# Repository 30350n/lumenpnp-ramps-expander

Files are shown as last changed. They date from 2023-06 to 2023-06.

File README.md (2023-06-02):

## LumenPnP Ramps Expander

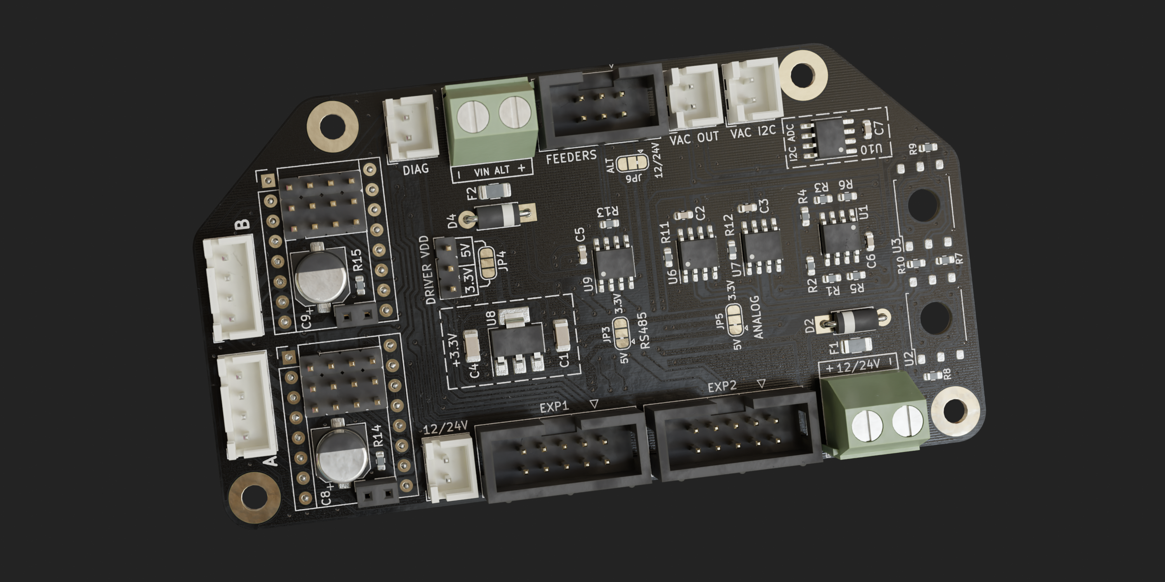
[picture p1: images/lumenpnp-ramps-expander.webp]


**Warning: This design hasn't been ordered/tested yet. Use at your own risk.**

I created this board to use as an expander for the MKS Gen L v2.1 I use to as a motherboard for
my LumenPnP.

It offers:

- 2 additional stepper drivers
- RS485 driver for feeders
- analog REV03 style vacuum sensors (I2C ADC option)
- extra power input to power feeders from a different (12V) PSU

While this was originally designed for the MKS Gen L v2.1, it should generally be compatible
with all ATmega2560 based RAMPS boards and maybe even other 3d printer boards that have the
12864 display expansion connectors.

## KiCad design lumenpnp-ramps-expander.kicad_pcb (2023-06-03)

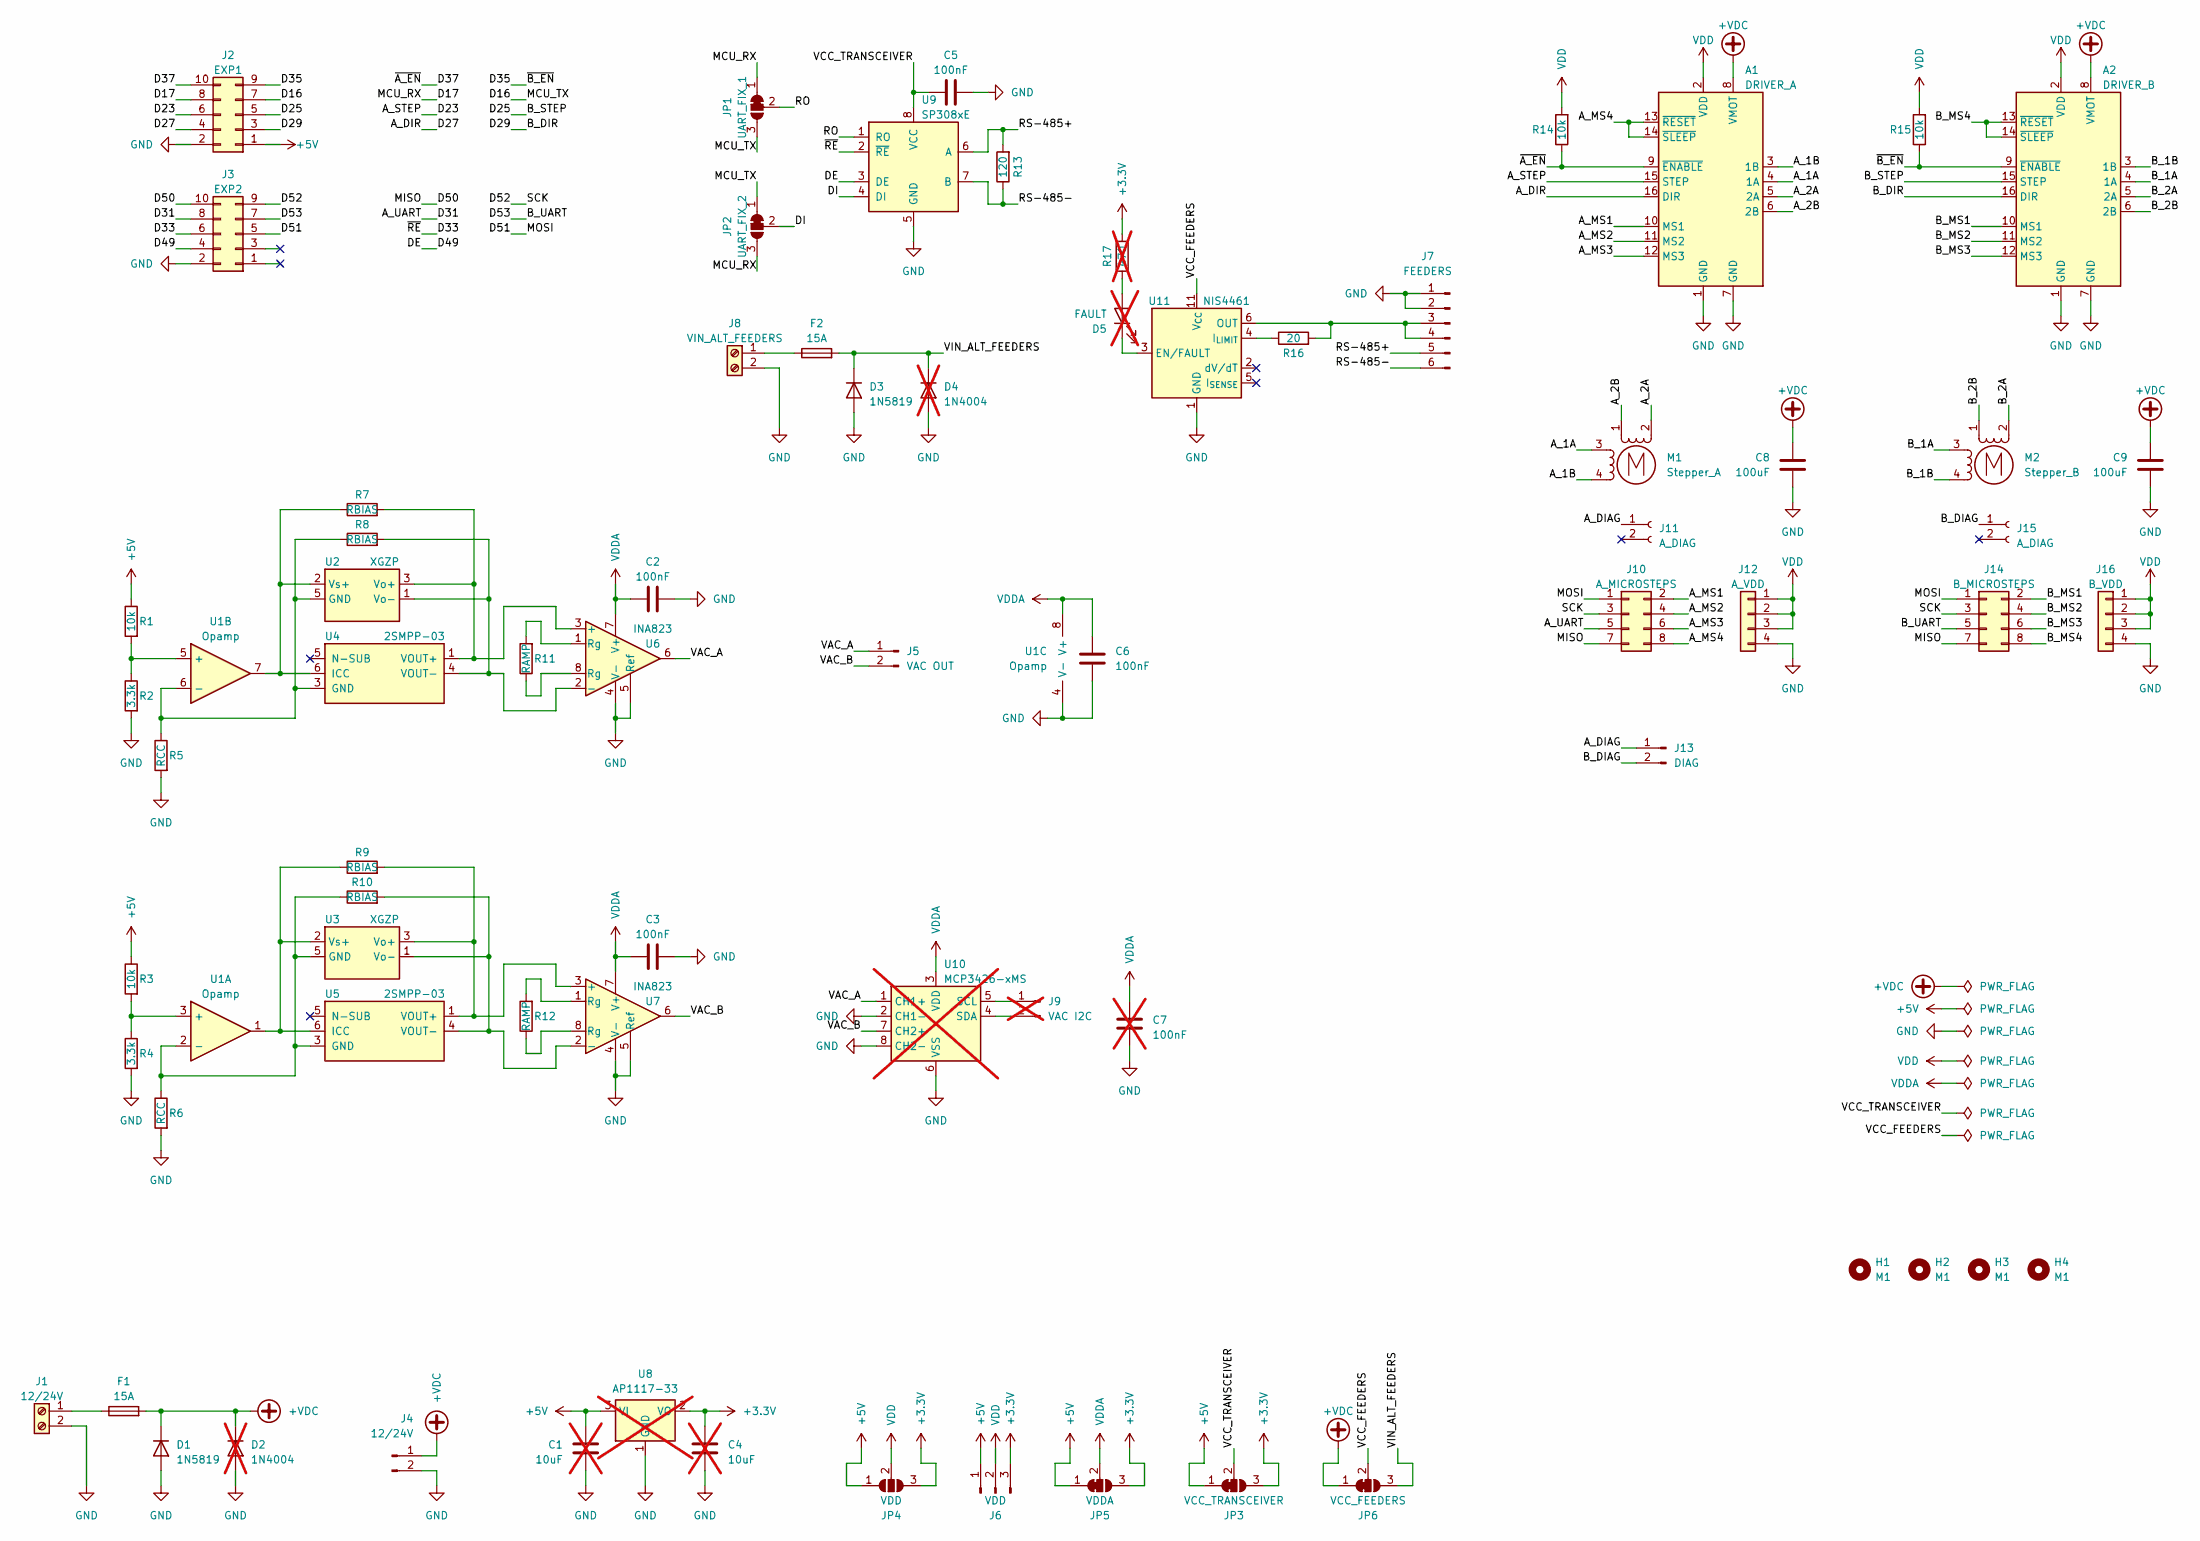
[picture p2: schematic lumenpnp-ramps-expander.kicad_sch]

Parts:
A1: DRIVER_A; Pololu_Breakout-16_15.2x20.3mm
A2: DRIVER_B; Pololu_Breakout-16_15.2x20.3mm
C1, C4: 10uF; C_1206_3216Metric; not fitted
C2, C3, C5, C6: 100nF; C_0603_1608Metric
C7: 100nF; C_0603_1608Metric; not fitted
C8, C9: 100uF; CP_Elec_6.3x7.7
D1, D3: 1N5819; D_SOD-123
D2, D4: 1N4004; D_DO-41_SOD81_P7.62mm_Horizontal; not fitted
D5: FAULT; LED_0603_1608Metric; not fitted
F1, F2: 15A; Fuse_1206_3216Metric
H1, H2, H3, H4: M1; MountingHole_3.2mm_M3_Pad
J1: 12/24V; TerminalBlock_Phoenix_MKDS-1,5-2-5.08_1x02_P5.08mm_Horizont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
J2: EXP1; IDC-Header_2x05_P2.54mm_Vertical
J3: EXP2; IDC-Header_2x05_P2.54mm_Vertical
J4: 12/24V; JST_XH_B2B-XH-A_1x02_P2.50mm_Vertical
J5: VAC OUT; JST_XH_B2B-XH-A_1x02_P2.50mm_Vertical
J6: VDD; PinHeader_1x03_P2.54mm_Vertical
J7: FEEDERS; IDC-Header_2x03_P2.54mm_Vertical
J8: VIN_ALT_FEEDERS; TerminalBlock_Phoenix_MKDS-1,5-2-5.08_1x02_P5.08mm_Horizont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
J9: VAC I2C; JST_XH_B2B-XH-A_1x02_P2.50mm_Vertical; not fitted
J10: A_MICROSTEPS; PinHeader_2x04_P2.54mm_Vertical
J11, J15: A_DIAG; PinSocket_1x02_P2.54mm_Vertical
J12: A_VDD; PinHeader_1x04_P2.54mm_Vertical
J13: DIAG; JST_XH_B2B-XH-A_1x02_P2.50mm_Vertical
J14: B_MICROSTEPS; PinHeader_2x04_P2.54mm_Vertical
J16: B_VDD; PinHeader_1x04_P2.54mm_Vertical
JP1: UART_FIX_1; SolderJumper-3_P1.3mm_Bridged12_RoundedPad1.0x1.5mm
JP2: UART_FIX_2; SolderJumper-3_P1.3mm_Bridged12_RoundedPad1.0x1.5mm
JP3: VCC_TRANSCEIVER; SolderJumper-3_P1.3mm_Bridged12_RoundedPad1.0x1.5mm
JP4: VDD; SolderJumper-3_P1.3mm_Open_RoundedPad1.0x1.5mm_NumberLabels
JP5: VDDA; SolderJumper-3_P1.3mm_Bridged12_RoundedPad1.0x1.5mm
JP6: VCC_FEEDERS; SolderJumper-3_P1.3mm_Bridged12_RoundedPad1.0x1.5mm
M1: Stepper_A; JST_XH_B4B-XH-A_1x04_P2.50mm_Vertical
M2: Stepper_B; JST_XH_B4B-XH-A_1x04_P2.50mm_Vertical
R1, R3, R14, R15: 10k; R_0603_1608Metric
R2, R4: 3.3k; R_0603_1608Metric
R5, R6: RCC; R_0603_1608Metric
R7, R8, R9, R10: RBIAS; R_0603_1608Metric
R11, R12: RAMP; R_0603_1608Metric
R13: 120; R_0603_1608Metric
R16: 20; R_0603_1608Metric
R17: 470; R_0603_1608Metric; not fitted
U1: Opamp; SOIC-8_3.9x4.9mm_P1.27mm
U2, U3: XGZP; SO-6_7x7mm_P2.54mm
U4, U5: 2SMPP-03
U6, U7: INA823; SOIC-8_3.9x4.9mm_P1.27mm
U8: AP1117-33; SOT-223-3_TabPin2; not fitted
U9: SP308xE; SOIC-8_3.9x4.9mm_P1.27mm
U10: MCP3426-xMS; SOIC-8_3.9x4.9mm_P1.27mm; not fitted
U11: NIS4461; WDFN-10-1EP_3x3mm_P0.5mm_EP1.8x2.5mm

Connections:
+3.3V: C4.1, J6.3, JP3.3 (B), JP4.3 (B), JP5.3 (B), R17.2, U8.2 (VO)
+5V: C1.1, J2.1, J6.1, JP3.1 (A), JP4.1 (A), JP5.1 (A), R1.1, R3.1, U8.3 (VI)
+VDC: A1.8 (VMOT), A2.8 (VMOT), C8.1, C9.1, D1.1 (K), D2.1 (K), F1.2, J4.1, JP6.1 (A)
/A_1A: A1.4 (1A), M1.3
/A_1B: A1.3 (1B), M1.4
/A_2A: A1.5 (2A), M1.2 (-)
/A_2B: A1.6 (2B), M1.1
/A_DIAG: J11.1, J13.1
/A_DIR: A1.16 (DIR), J2.4
/A_MS1: A1.10 (MS1), J10.2
/A_MS2: A1.11 (MS2), J10.4
/A_MS3: A1.12 (MS3), J10.6
/A_MS4: A1.13 (~RESET), A1.14 (~SLEEP), J10.8
/A_STEP: A1.15 (STEP), J2.6
/A_UART: J3.8, J10.5
/B_1A: A2.4 (1A), M2.3
/B_1B: A2.3 (1B), M2.4
/B_2A: A2.5 (2A), M2.2 (-)
/B_2B: A2.6 (2B), M2.1
/B_DIAG: J13.2, J15.1
/B_DIR: A2.16 (DIR), J2.3
/B_MS1: A2.10 (MS1), J14.2
/B_MS2: A2.11 (MS2), J14.4
/B_MS3: A2.12 (MS3), J14.6
/B_MS4: A2.13 (~RESET), A2.14 (~SLEEP), J14.8
/B_STEP: A2.15 (STEP), J2.5
/B_UART: J3.7, J14.5
/D16: J2.7, JP1.3 (B), JP2.1 (A)
/D17: J2.8, JP1.1 (A), JP2.3 (B)
/D33: J3.6, U9.2 (~RE)
/D35: A2.9 (~ENABLE), J2.9, R15.1
/D37: A1.9 (~ENABLE), J2.10, R14.1
/D49: J3.4, U9.3 (DE)
/D50: J3.10, J10.7, J14.7
/D51: J3.5, J10.1, J14.1
/D52: J3.9, J10.3, J14.3
/DI: JP2.2 (C), U9.4 (DI)
/RO: JP1.2 (C), U9.1 (RO)
/RS-485+: J7.5, R13.2, U9.6 (A)
/RS-485-: J7.6, R13.1, U9.7 (B)
/VAC_A: J5.1, U6.6, U10.1 (CH1+)
/VAC_B: J5.2, U7.6, U10.7 (CH2+)
/VCC_FEEDERS: JP6.2 (C), U11.11 (V_{CC})
/VCC_TRANSCEIVER: C5.1, JP3.2 (C), U9.8 (VCC)
/VIN_ALT_FEEDERS: D3.1 (K), D4.1 (K), F2.2, JP6.3 (B)
GND: A1.1 (GND), A1.7 (GND), A2.1 (GND), A2.7 (GND), C1.2, C2.2, C3.2, C4.2, C5.2, C6.2, C7.2, C8.2, C9.2, D1.2 (A), D2.2 (A), D3.2 (A), D4.2 (A), J1.2, J2.2, J3.2, J4.2, J7.1, J7.2, J8.2, J12.4, J16.4, R2.2, R4.2, R5.2, R6.2, U1.4 (V-), U6.4 (V-), U6.5 (Ref), U7.4 (V-), U7.5 (Ref), U8.1 (GND), U9.5 (GND), U10.2 (CH1-), U10.6 (VSS), U10.8 (CH2-), U11.1 (GND)
unnamed: D5.2 (A), R17.1
unnamed: D5.1 (K), U11.3 (EN/FAULT)
unnamed: F1.1, J1.1
unnamed: J7.3, J7.4, R16.2, U11.6 (OUT), U11.7 (OUT), U11.8 (OUT), U11.9 (OUT), U11.10 (OUT)
unnamed: F2.1, J8.1
unnamed: J9.1, U10.5 (SCL)
unnamed: J9.2, U10.4 (SDA)
unnamed: R11.1, U6.8 (Rg)
unnamed: R11.2, U6.1 (Rg)
unnamed: R12.1, U7.8 (Rg)
unnamed: R12.2, U7.1 (Rg)
unnamed: R3.2, R4.1, U1.3 (+)
unnamed: R6.1, R10.1, U1.2 (-), U3.5 (GND), U5.3 (GND)
unnamed: R1.2, R2.1, U1.5 (+)
unnamed: R5.1, R8.1, U1.6 (-), U2.5 (GND), U4.3 (GND)
unnamed: R7.2, U2.3 (Vo+), U4.1 (VOUT+), U6.3 (+)
unnamed: R7.1, U1.7, U2.2 (Vs+), U4.6 (ICC)
unnamed: R9.2, U3.3 (Vo+), U5.1 (VOUT+), U7.3 (+)
unnamed: R9.1, U1.1, U3.2 (Vs+), U5.6 (ICC)
unnamed: R8.2, U2.1 (Vo-), U2.6 (Vo-), U4.4 (VOUT-), U6.2 (-)
unnamed: R10.2, U3.1 (Vo-), U3.6 (Vo-), U5.4 (VOUT-), U7.2 (-)
unnamed: R16.1, U11.4 (I_{LIMIT})
VDD: A1.2 (VDD), A2.2 (VDD), J6.2, J12.1, J12.2, J12.3, J16.1, J16.2, J16.3, JP4.2 (C), R14.2, R15.2
VDDA: C2.1, C3.1, C6.1, C7.1, JP5.2 (C), U1.8 (V+), U6.7 (V+), U7.7 (V+), U10.3 (VDD)

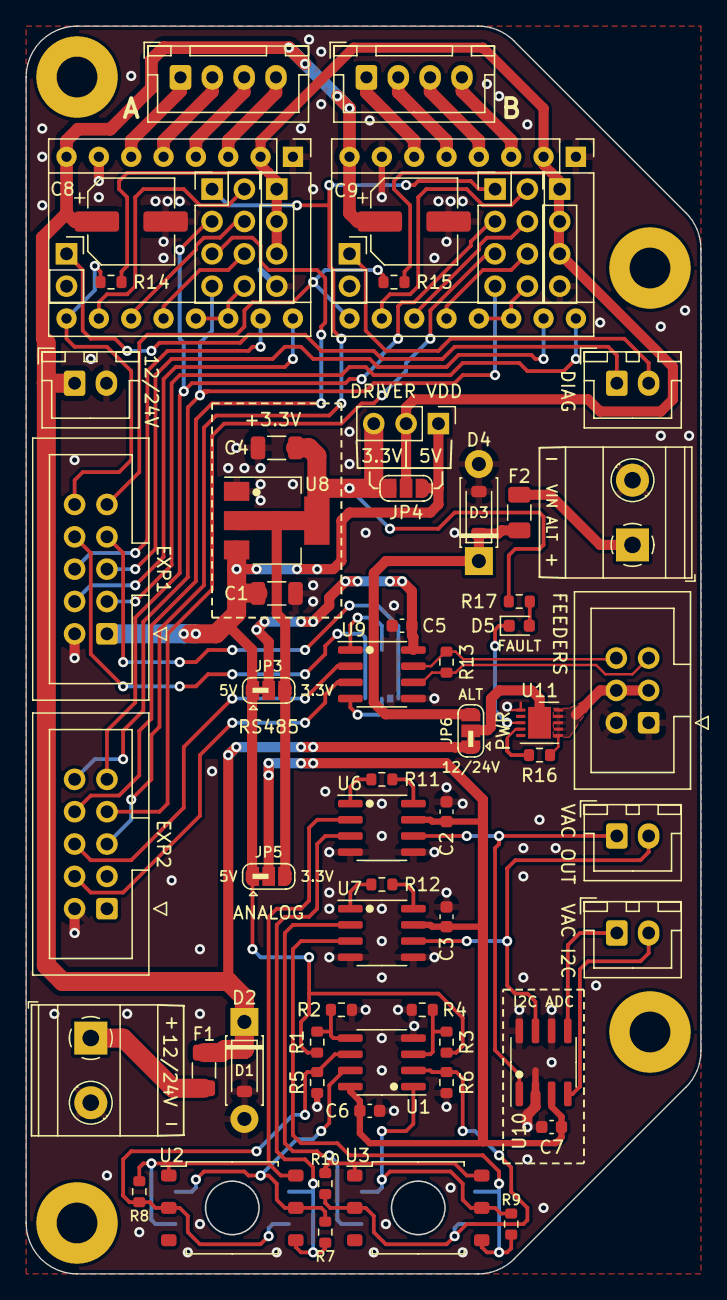
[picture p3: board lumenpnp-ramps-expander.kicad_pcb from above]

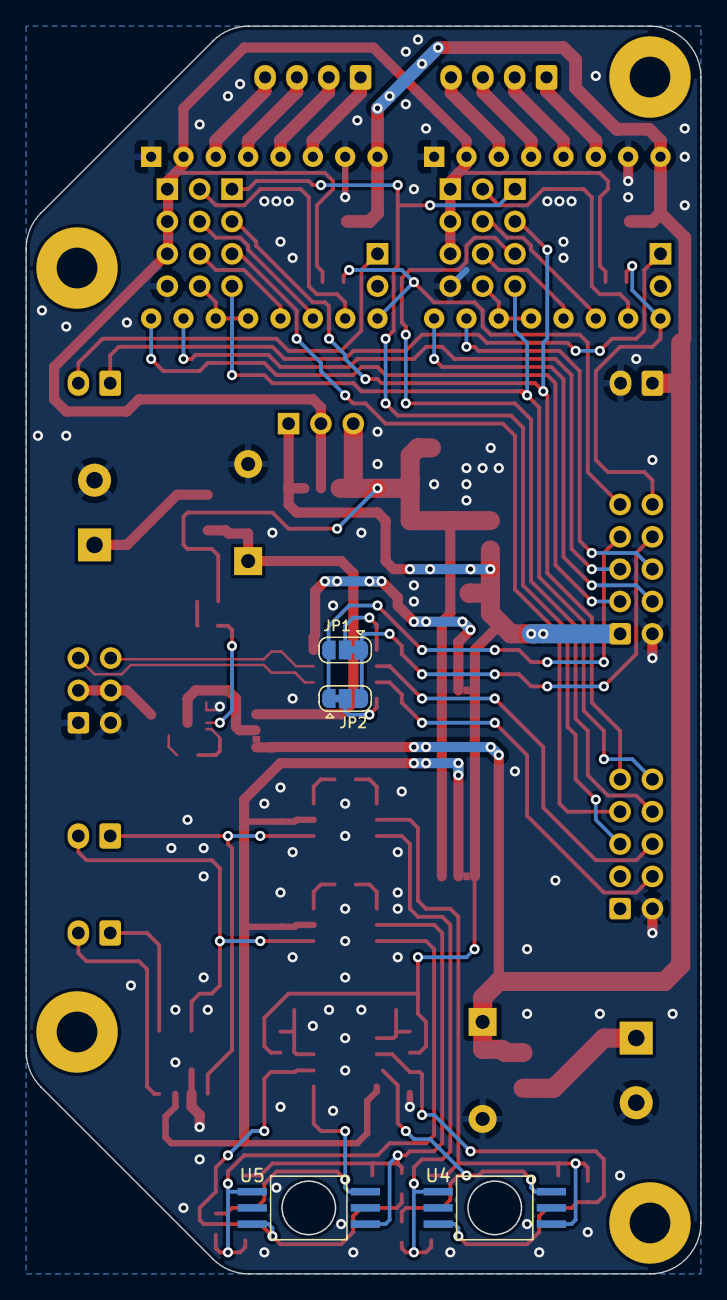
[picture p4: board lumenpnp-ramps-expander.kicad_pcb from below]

Board: 2 copper layers, 53.0 x 98.0 mm, 74 parts (2 on the bottom side), 70 nets.
